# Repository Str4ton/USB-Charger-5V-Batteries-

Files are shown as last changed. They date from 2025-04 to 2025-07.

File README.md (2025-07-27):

# USB-Charger-5V-Batteries
A USB Charger for 5V Li-Ion batteries. It is designed to charge from a usb port, or something that will give 5V, 0.5A.

The circuit has a few protection circuits:
- A current limiter circuit so that the battery charges safely.
- A reverse polarity protection in case the battery is plugged in backwards that will not allow the circuit to start.
- A circuit that will stop the charging once it's done.

The PIC18 is used to monitor the charging and stop it when it's done and to light the 2 LEDs, one for when the charging is in process and the other for when it's done.\
The PIC18 is utilised more for convenience as the entire circuit could have been fully analog.

The schematics can be found in the [Charger USB.pdf](https://github.com/Str4ton/USB-Charger-5V-Batteries-/blob/main/Charger%20USB.pdf) file.

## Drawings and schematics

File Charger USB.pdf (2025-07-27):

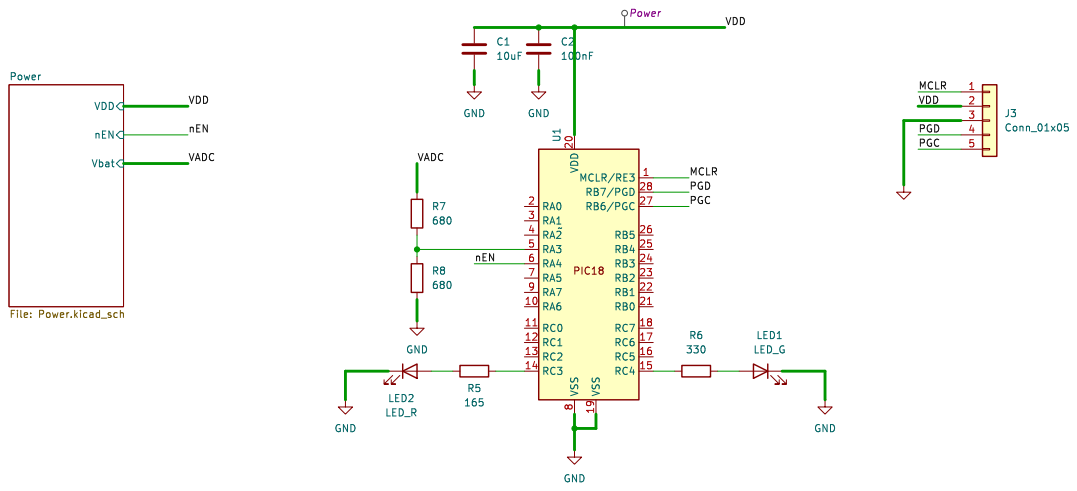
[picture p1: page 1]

8 VSS 19 MCLR/RE3 1 RB7/PGD 28 RB6/PGC 27 RB5 26 RB4 25 RB3 24 RB2 23 RB1 22 RB0 21 RC7 18 RC6 17 RC5 16 RC4 15 U1 ~ C1

Id: 1/2 Title: File: Charger USB.kicad_sch Sheet: /

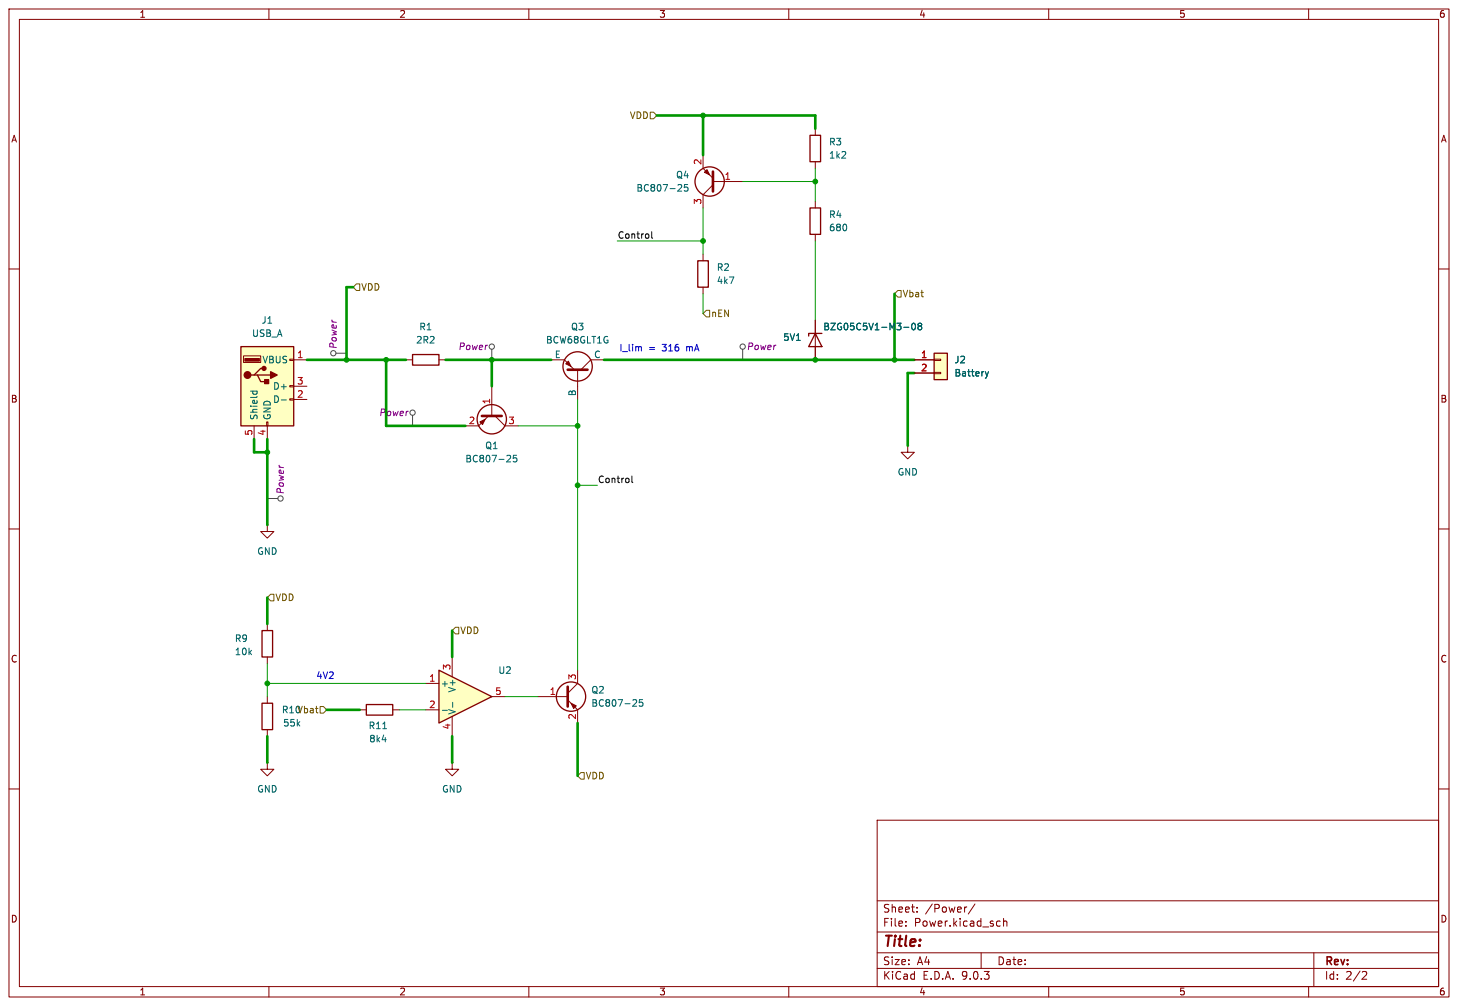
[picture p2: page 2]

Id: 2/2 Title: File: Power.kicad_sch Sheet: /Power/

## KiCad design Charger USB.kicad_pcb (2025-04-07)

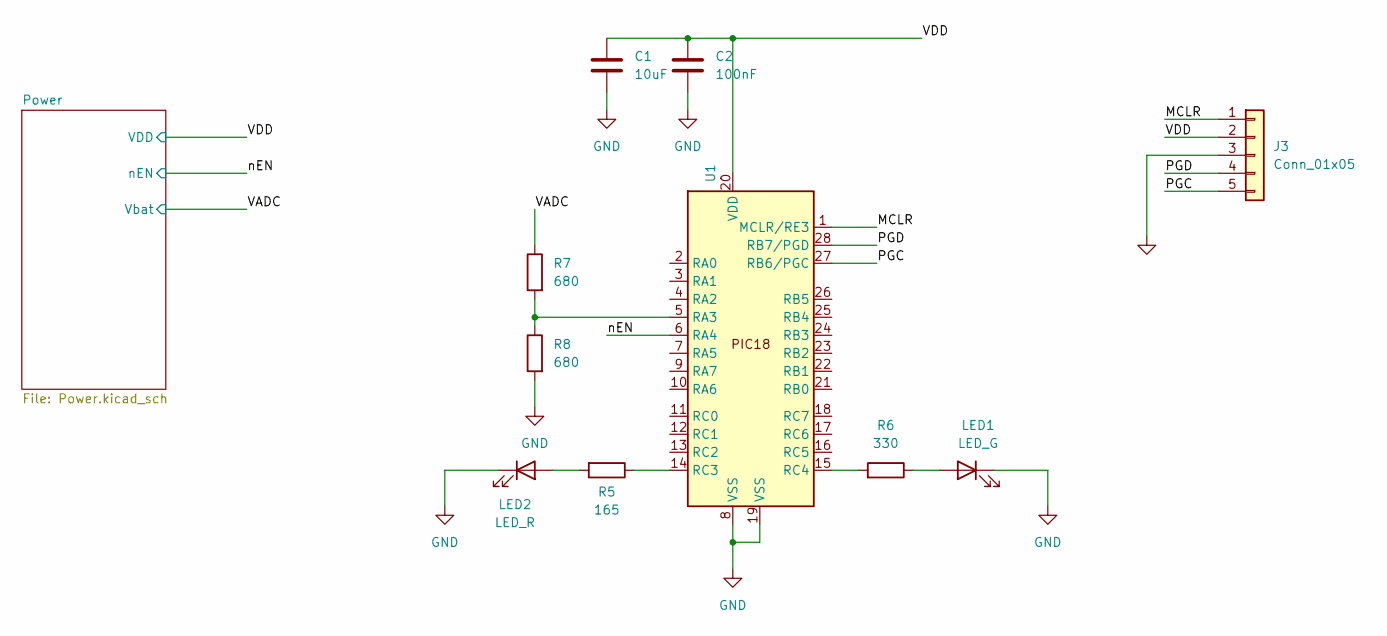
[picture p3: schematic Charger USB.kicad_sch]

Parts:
C1: 10uF; C_0805_2012Metric; Part# CL21A106KPFNNNE
C2: 100nF; C_0603_1608Metric; Part# 0402ZD104KAT2A
J3: Conn_01x05; PinSocket_1x05_P2.54mm_Vertical
LED1: LED_G; LED_D5.0mm; Part# LTL-307G
LED2: LED_R; LED_D5.0mm; Part# FYL-5013SRD1C
R5: 165; R_0805_2012Metric; Part# RC0805FR-07165RL
R6: 330; R_0603_1608Metric; Part# 0603SAF3300T5E
R7, R8: 680; R_1206_3216Metric; Part# 1206S4F1100T5E
U1: SOIC-28W_7.5x17.9mm_P1.27mm; Part# PIC18F26K42-I/SO

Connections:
/MCLR: J3.1, U1.1 (MCLR/RE3)
/PGC: J3.5, U1.27 (RB6/PGC)
/PGD: J3.4, U1.28 (RB7/PGD)
/VADC: R7.1; also elsewhere on the board
/VDD: C1.1, C2.1, J3.2, U1.20 (VDD); also elsewhere on the board
/nEN: U1.6 (RA4); also elsewhere on the board
GND: C1.2, C2.2, J3.3, LED1.1 (K), LED2.1 (K), R8.2, U1.8 (VSS), U1.19 (VSS); also elsewhere on the board
unnamed: LED1.2 (A), R6.1
unnamed: LED2.2 (A), R5.2
unnamed: R7.2, R8.1, U1.5 (RA3)
unnamed: R5.1, U1.14 (RC3)
unnamed: R6.2, U1.15 (RC4)

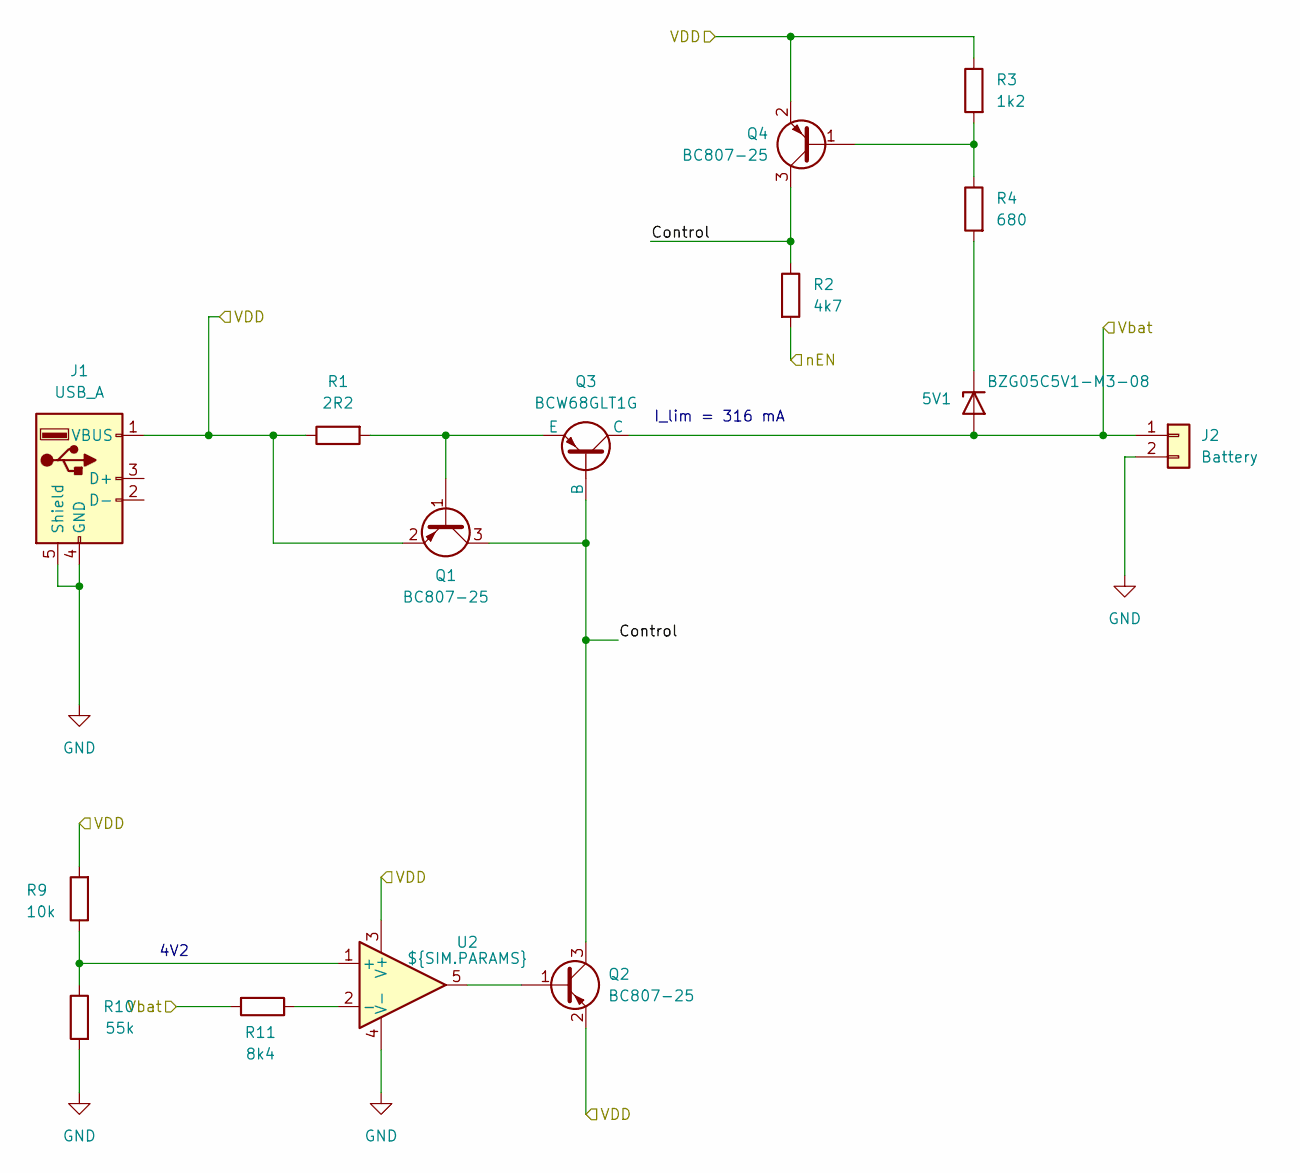
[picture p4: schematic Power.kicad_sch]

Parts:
BZG05C5V1-M3-08: 5V1; D_0201_0603Metric; Part# BZG05C5V1-M3-08
J1: USB_A; USB_A_Receptacle_GCT_USB1046
J2: Battery; PinHeader_1x02_P2.54mm_Vertical
Q1, Q2, Q4: BC807-25; SOT-23; Part# BC807-25
Q3: BCW68GLT1G; SOT-23; Part# BCW68GLT1G
R1: 2R2; R_0402_1005Metric; Part# ERJ2GEJ2R0X
R2: 4k7; R_0603_1608Metric; Part# RC0603FR-071KL
R3: 1k2; R_1206_3216Metric; Part# 1206S4F1100T5E
R4: 680; R_1206_3216Metric; Part# 1206S4F1100T5E
R9: 10k; R_0603_1608Metric; Part# RC0603FR-071KL
R10: 55k; R_0603_1608Metric; Part# RC0603FR-071KL
R11: 8k4; R_0805_2012Metric; Part# RC0603FR-071KL
U2: ${SIM.PARAMS}; SOT23-5L_1P75X3P05X0P95_STM

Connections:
/Power/Control: Q1.3 (C), Q2.3 (C), Q3.2 (B), Q4.3 (C), R2.1
/VADC: BZG05C5V1-M3-08.2 (A), J2.1, Q3.1 (C), R11.2; also elsewhere on the board
/VDD: J1.1 (VBUS), Q1.2 (E), Q2.2 (E), Q4.2 (E), R1.1, R3.1, R9.2, U2.3 (V+); also elsewhere on the board
/nEN: R2.2; also elsewhere on the board
GND: J1.4 (GND), J1.5 (Shield), J2.2, R10.2, U2.4 (V-); also elsewhere on the board
unnamed 8: BZG05C5V1-M3-08.1 (K), R4.2; also elsewhere on the board
unnamed: Q1.1 (B), Q3.3 (E), R1.2
unnamed: Q2.1 (B), U2.5
unnamed: Q4.1 (B), R3.2, R4.1
unnamed: R9.1, R10.1, U2.1 (+)
unnamed: R11.1, U2.2 (-)

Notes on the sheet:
4V2
I_lim = 316 mA

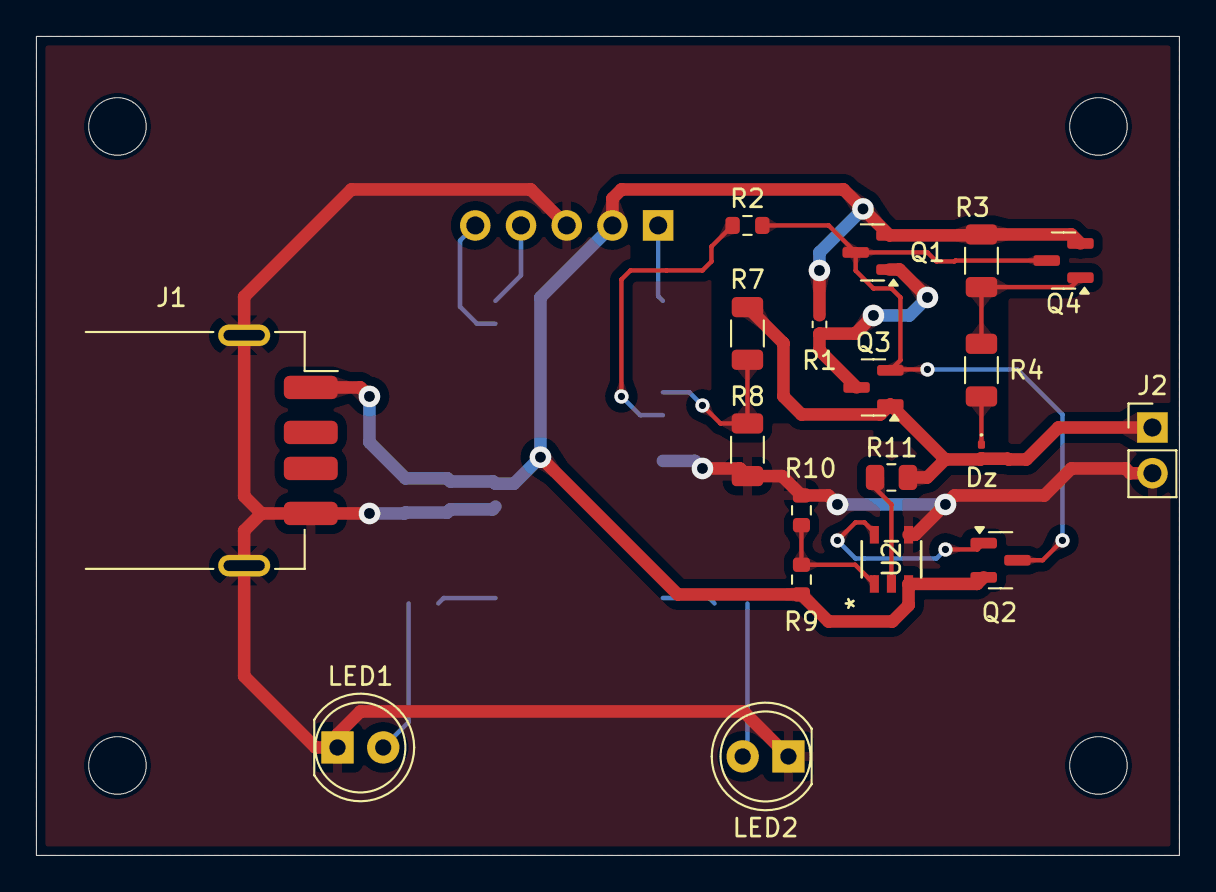
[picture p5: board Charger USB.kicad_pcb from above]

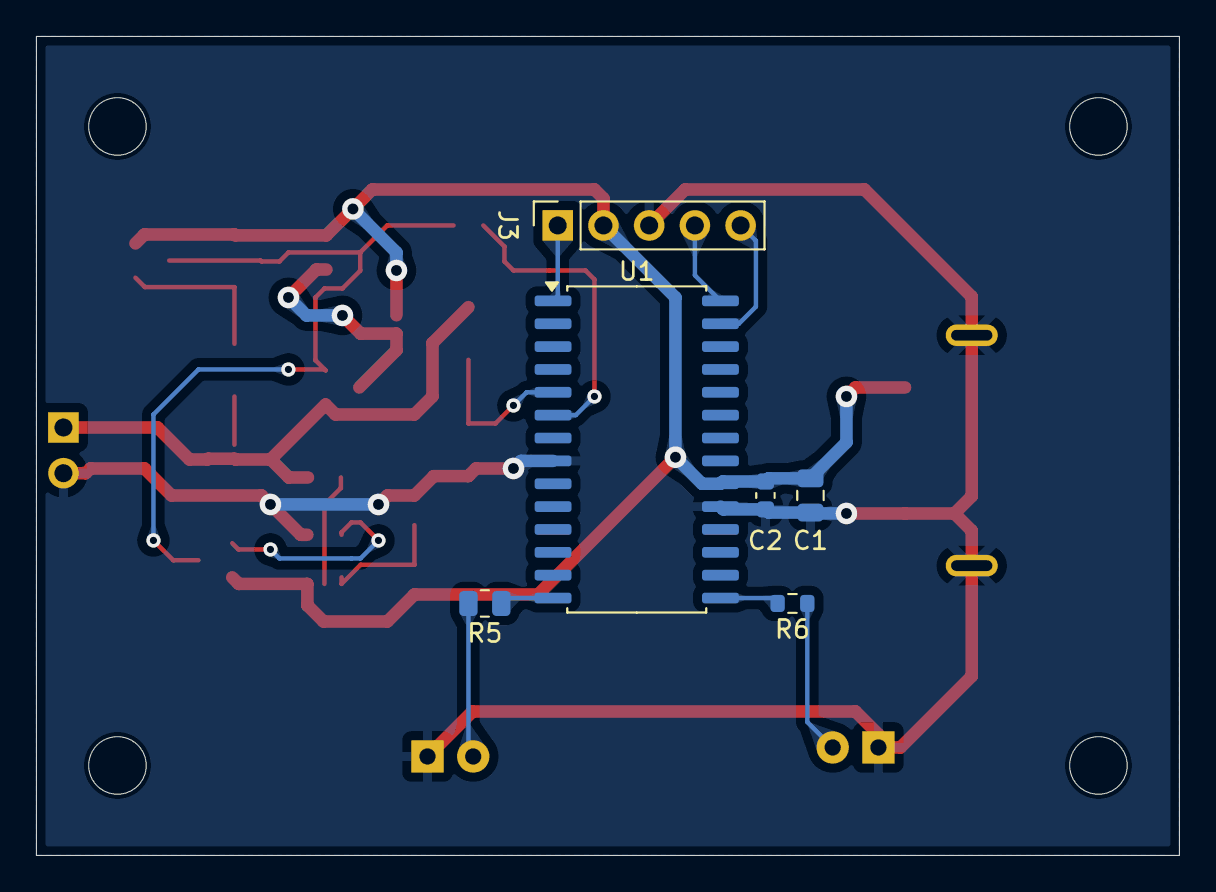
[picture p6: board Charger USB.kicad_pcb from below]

Board: 2 copper layers, 63.5 x 45.5 mm, 25 parts (6 on the bottom side), 19 nets.

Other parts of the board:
Dz: 5V1; D_0201_0603Metric

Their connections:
/VADC: Dz.2 (A); also elsewhere on the board
unnamed 8: Dz.1 (K); also elsewhere on the board
